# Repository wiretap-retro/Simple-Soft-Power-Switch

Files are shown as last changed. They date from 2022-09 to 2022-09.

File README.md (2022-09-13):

# Simple Soft Power Switch
A circuit for providing a power switch that latches, utilizing a momentary push button.

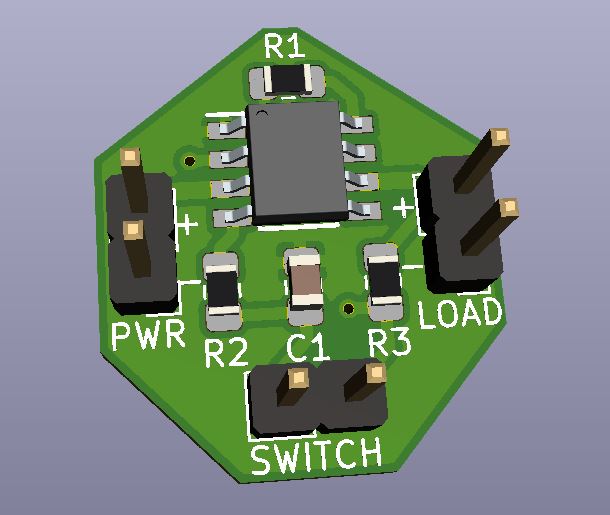
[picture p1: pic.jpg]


## Intro
This is a simple soft power switch that latches, using a momentary push button. It is found in many different devices from kids toys to consumer power supplies. I took apart an old electronic basketball hoop toy of my son's to reverse engineer the power switch circuit. This circuit is cheap and simple, costing less than a bottle of Coke. From the datasheet, it can handle 5-18VDC with approximately 4 amps of current. This is a neat design to use in small projects where you want a momentary push button for powering on and off your device. This does not do voltage step-up/step-down. What you feed into the power header is what comes out on the load side.

## Assembly / Install
* If used, the provided circuit board can be ordered from a PCB fabricator of your choice. (JLCPCB, PCBway, OSH Park, etc.)
* The components can be found from a wide variety of retailers. (Mouser, Digikey, RS, etc.)
* Solder the SMD components first. Pay attention to the orientation of the IRF7319.
* Solder the pin headers.
* Hook up a momentary switch to the SWITCH header.
* Hook up 5VDC to 18VDC to the PWR header.
* Hook up the device you want to power to the LOAD header.
* Press the momentary button once and your device turns on. Press it again and the device turns off.

## Important Note
With the provided PCB design with the small pin headers, use only low power IoT type devices. Don't melt your wiring and start a fire. This circuit is more intended to be used as an integration into other projects where you need a switched load.

## Misc
This project is open source. Feel free to do what you want with it.

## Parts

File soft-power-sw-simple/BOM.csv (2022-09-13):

Reference | Value | Footprint | Manufacturer_Name | Manufacturer_Part_Number | Mouser Part Number
C1 | 1uF | Capacitor_SMD:C_0805_2012Metric_Pad1.15x1.40mm_HandSolder
J1 | PWR | Connector_PinHeader_2.54mm:PinHeader_1x02_P2.54mm_Vertical
J2 | SWITCH | Connector_PinHeader_2.54mm:PinHeader_1x02_P2.54mm_Vertical
J3 | LOAD | Connector_PinHeader_2.54mm:PinHeader_1x02_P2.54mm_Vertical
Q1 | IRF7319TRPBF | SOIC127P600X175-8N | Infineon | IRF7319TRPBF | 942-IRF7319TRPBF
R1 | 10k | Resistor_SMD:R_0805_2012Metric_Pad1.15x1.40mm_HandSolder
R2 | 100k | Resistor_SMD:R_0805_2012Metric_Pad1.15x1.40mm_HandSolder
R3 | 10k | Resistor_SMD:R_0805_2012Metric_Pad1.15x1.40mm_HandSolder

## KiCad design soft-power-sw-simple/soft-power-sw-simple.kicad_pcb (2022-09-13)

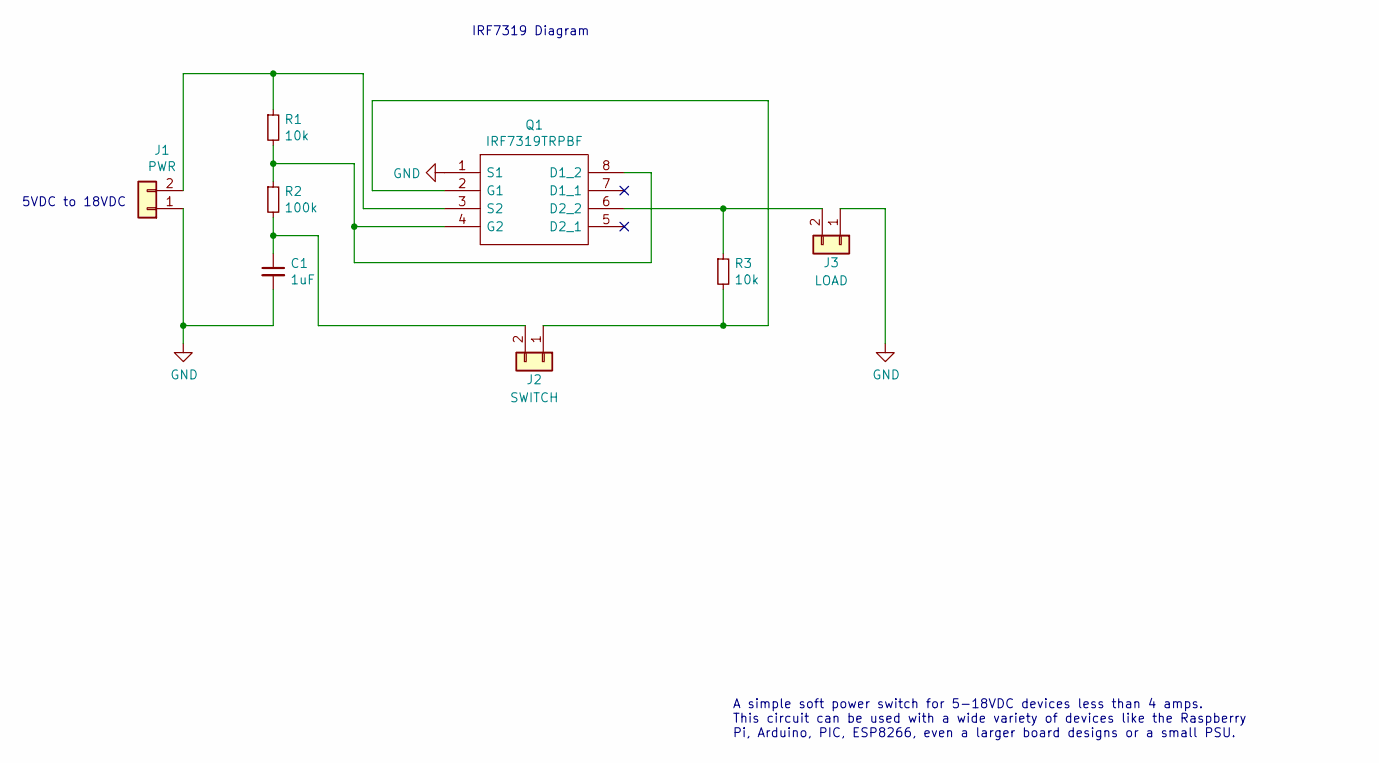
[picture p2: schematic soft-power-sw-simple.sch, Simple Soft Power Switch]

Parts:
C1: 1uF; C_0805_2012Metric_Pad1.15x1.40mm_HandSolder
J1: PWR; PinHeader_1x02_P2.54mm_Vertical
J2: SWITCH; PinHeader_1x02_P2.54mm_Vertical
J3: LOAD; PinHeader_1x02_P2.54mm_Vertical
Q1: IRF7319TRPBF; SOIC127P600X175-8N; Mouser Part Number 942-IRF7319TRPBF
R1, R3: 10k; R_0805_2012Metric_Pad1.15x1.40mm_HandSolder
R2: 100k; R_0805_2012Metric_Pad1.15x1.40mm_HandSolder

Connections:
GND: C1.2, J1.1, J3.1, Q1.1 (S1)
unnamed: C1.1, J2.2, R2.2
unnamed: J1.2, Q1.3 (S2), R1.1
unnamed: J2.1, Q1.2 (G1), R3.2
unnamed: J3.2, Q1.6 (D2_2), R3.1
unnamed: Q1.4 (G2), Q1.8 (D1_2), R1.2, R2.1

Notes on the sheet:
IRF7319 Diagram
5VDC to 18VDC
A simple soft power switch for 5-18VDC devices less than 4 amps. This circuit can be used with a wide variety of devices like the Raspberry Pi, Arduino, PIC, ESP8266, even a larger board designs or a small PSU.

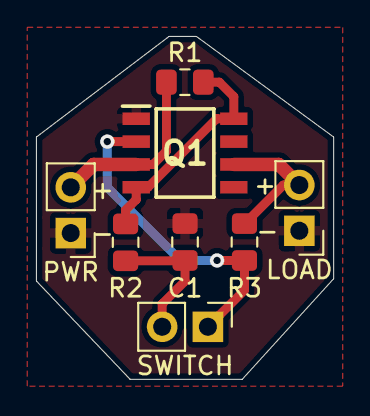
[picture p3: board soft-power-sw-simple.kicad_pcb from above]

Board: 2 copper layers, 16.5 x 19.0 mm, 8 parts (0 on the bottom side), 6 nets.
